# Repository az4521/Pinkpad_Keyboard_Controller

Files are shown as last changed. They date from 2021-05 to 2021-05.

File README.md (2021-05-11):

# Pinkpad_Keyboard_Controller
 This repo contains all the files that are needed to make the [Pinkpad](https://crafty.moe/pinkpad.htm)'s thinkpad X61 keyboard controller.
 
 BOM:
```
1x 0543630489 connector
1x Teensy LC
2x BSS138 (or compatible) sot23 NFET
4x 0603 10K Resistor
2x 0.1uf 0603 Capacitor
```

If you'd like to order the unpopulated board directly, I recommend ordering [This OSHPark project](https://oshpark.com/shared_projects/3l395XbG)

This board is based on [HDR/USB_Laptop_Keyboard_Controller](https://github.com/HDR/USB_Laptop_Keyboard_Controller), I've just removed the need for a reset generator in exchange for getting rid of the caps lock LED.

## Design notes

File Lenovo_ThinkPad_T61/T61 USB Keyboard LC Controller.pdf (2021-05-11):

This document will describe how I made a USB keyboard from a Lenovo ThinkPad T61 keyboard using a Teensy LC microcontroller. All associated files are in the Teensy LC folder under the Lenovo_Thinkpad_T61 folder at my Github repo. (https://github.com/thedalles77/USB_Laptop_Keyboard_Controller/tree/master/Example_Keyboards/Lenovo_ThinkPad_T61/) I initially designed a board for a Teensy 3.2 which taught me a lot about the keyboard. I used that information to design a Teensy LC board with the following changes from the 3.2 board.

1. The TrackPoint Clock and Data signals are translated to 5 volts with two BSS138 FETs and four 10K pullups. This was done because the Teensy LC does not have 5 volt tolerant I/Os.
2. The TrackPoint power-on-reset signal is created from a TLV810MDBZR in order to not use a Teensy I/O pin.
3. The Fn key switch is wired into the matrix by connecting FPC pin 1 to pin 11 and pin 36 to pin 20. Placing the Fn switch into the matrix was done to not use a Teensy I/O pin.
4. The Caps Lock signal on I/O #13 has a 715 ohm dropping resistor for a 2ma (low current) LED. This was done so the 3ma LED on the Teensy doesn’t need to be removed.
5. I rearranged the Teensy and FPC connector locations on the board to get away from the mounting post on the bottom of the keyboard. This layout change also keeps the circuit board underneath the keyboard so it can be hidden if mounting on a block of wood.

The picture below shows the Teensy LC circuit board connected to a ThinkPad T61 keyboard.

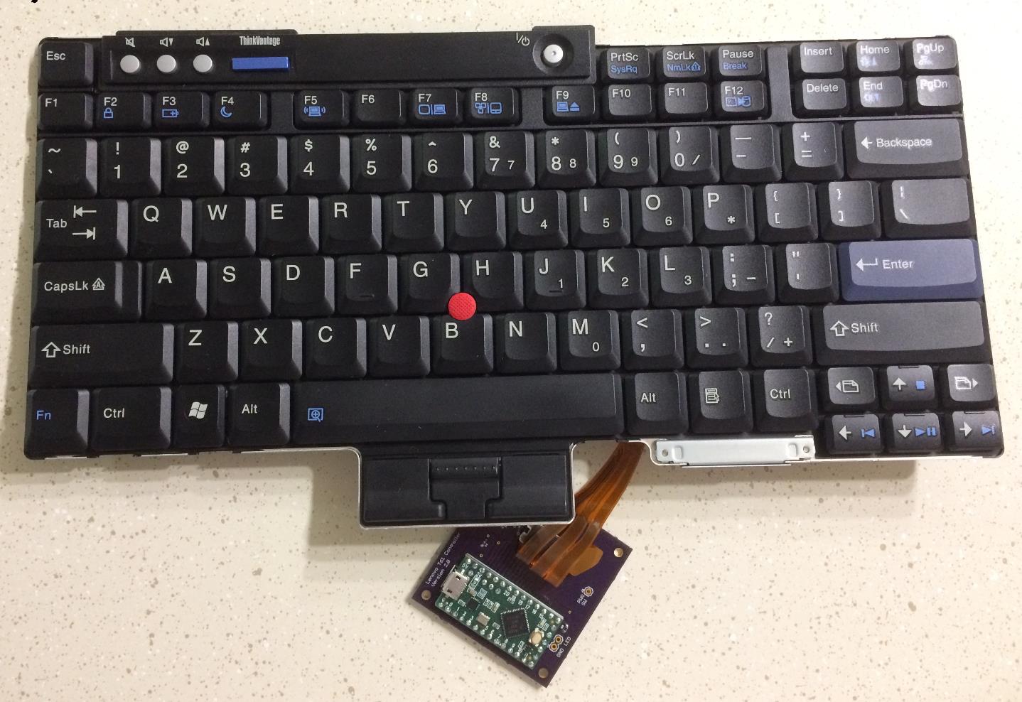
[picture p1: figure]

T61_LC_Scanner.brd file was sent to OSH Park for fabrication. The bare and assembled board is shown below. The Eagle board and schematic files are in the Eagle folder (https://github.com/thedalles77/USB_Laptop_Keyboard_Controller/tree/master/Example_Keyboards/Lenovo_ThinkPad_T61/Teensy%20LC/Eagle) at my Github repo.

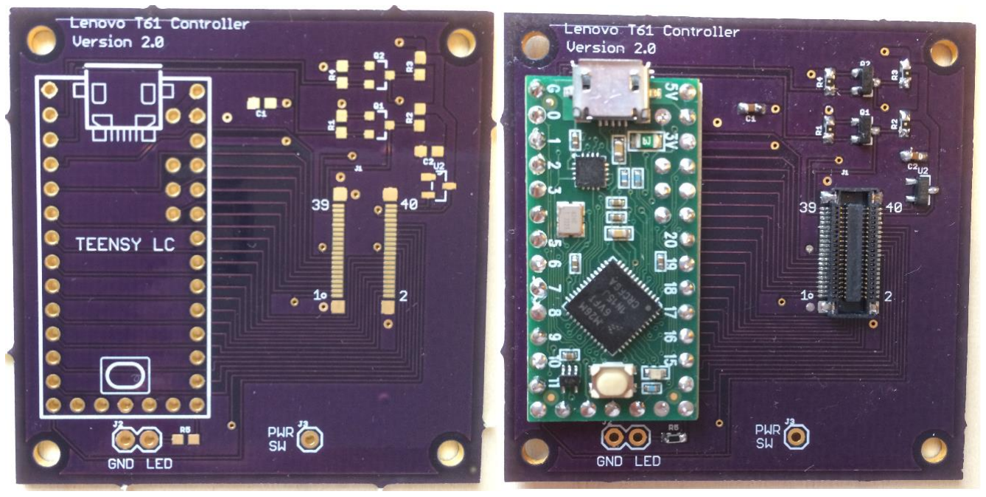
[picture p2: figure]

Parts List:
T61_LC_Scanner circuit board as shown above
Teensy LC from Amazon
Header pins and wire to connect the Teensy to the board

Digikey parts:
WM6787CT-ND 40 Pin Keyboard Connector Qty 1

TLV810MDBZR 4.38 Volt Reset Generator SOT23 Qty 1

BSS138CT-ND NFET SOT23 Qty 2

10K Resistors 0603 ¼ Watt 1% Qty 4

715 ohm Resistor 0603 1/10 Watt 1% Qty 1

0.1uf Ceramic Capacitor 0603 50V Y5V Qty 2

754-1592-ND 2ma Yellow LED axial lead Qty 1

Part placement and description shown below.

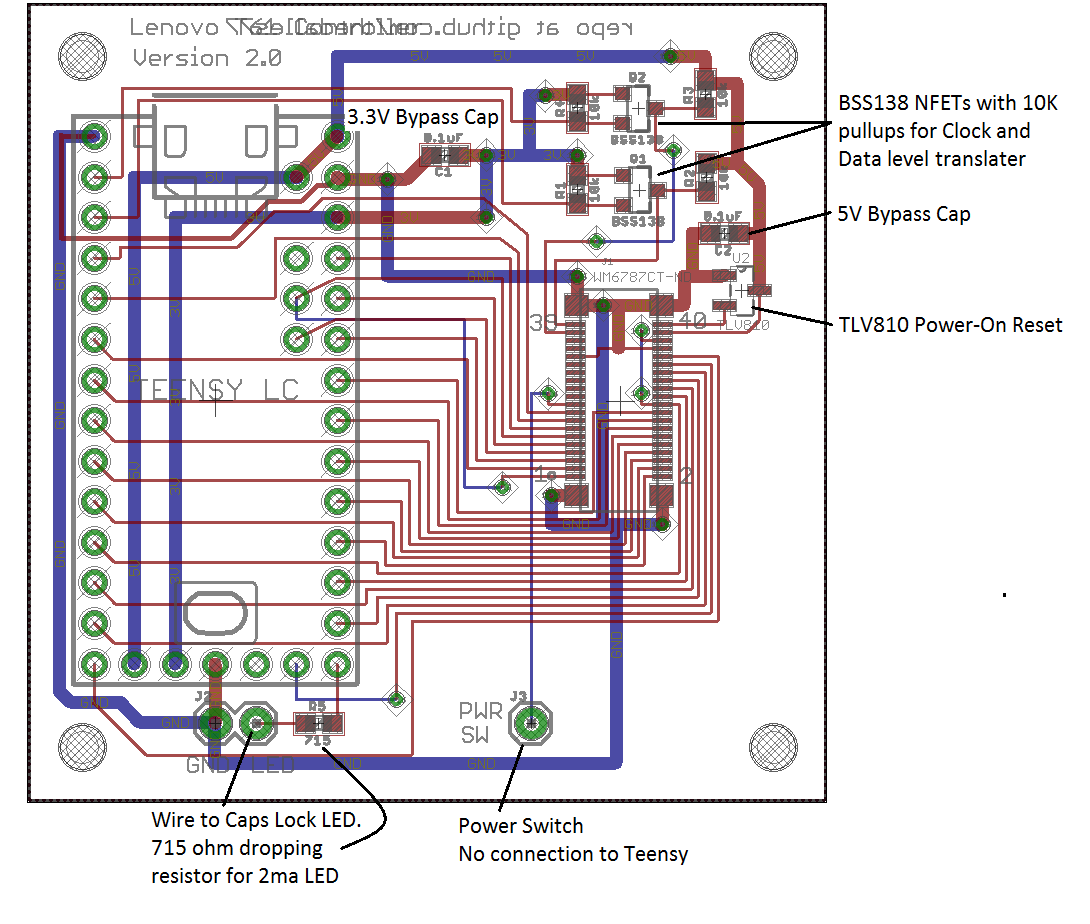
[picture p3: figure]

The WM6787CT-ND connector from Digikey will work with the Lenovo T61 keyboard but I did have some trouble with alignment, as originally discovered with the Teensy 3.2 board. Once I got the plug correctly installed in the socket, it worked fine so I don’t view this as a big problem. The alternative to using the Digikey connector is to search for the original JAE AA01B_S040VA1 connector or unsolder it from a broken motherboard. Forum posters have reported that the original connector is hard to find and only available in large lot sizes.

The keyboard connections to the Teensy LC pins are shown below.
Lenovo ThinkPad T61 FPC Connector | Teensy LC I/O number | T61 Schematic Signal Name
1 | 24 | HOTKEY
2 | 16 | DRV<4>
3 | 4 | SENSE<5>
4 | 8 | DRV<5>
5 | 21 | SENSE<0>
6 | 17 | DRV<8>

7 | 25 | SENSE<3>
8 | 7 | DRV<6>
9 | 22 | SENSE<2>
10 | 18 | DRV<3>
11 | 24 | SENSE<4>
12 | 6 | DRV<7>
13 | 23 | SENSE<1>
14 | 19 | DRV<2>
15 | 3 | SENSE<6>
16 | 5 | DRV<10>
17 | 2 | SENSE<7>
18 | 20 | DRV<1>
19 | PWR SW Pad | PWR SW
20 | 9 | DRV<9>
21 | No connect | NC
22 | 15 | DRV<0>
23 | No connect | NC
24 | 10 | DRV<11>
25 | No connect | KBDID0
26 | 14 | DRV<14>
27 | No connect | KBDID1
28 | 11 | DRV<12>
29 | No connect | KBDID2
30 | 26 | DRV<15>
31 | Teensy GND | KBDID RTN
32 | 12 | DRV<13>
33 | No connect | NC
34 | Teensy GND | PWR SW RTN
35 | No connect | NC
36 | 9 | HOTKEY RTN
37 | 0 | TP_DATA
38 | Teensy 5V | TP_5V
39 | 1 | TP_CLK
40 | TLV810 | TP_RESET
41 thru 44 | Teensy GND | GND

The Eagle schematic for the connections on the circuit board is given below. This schematic is in the Eagle folder at my repo.

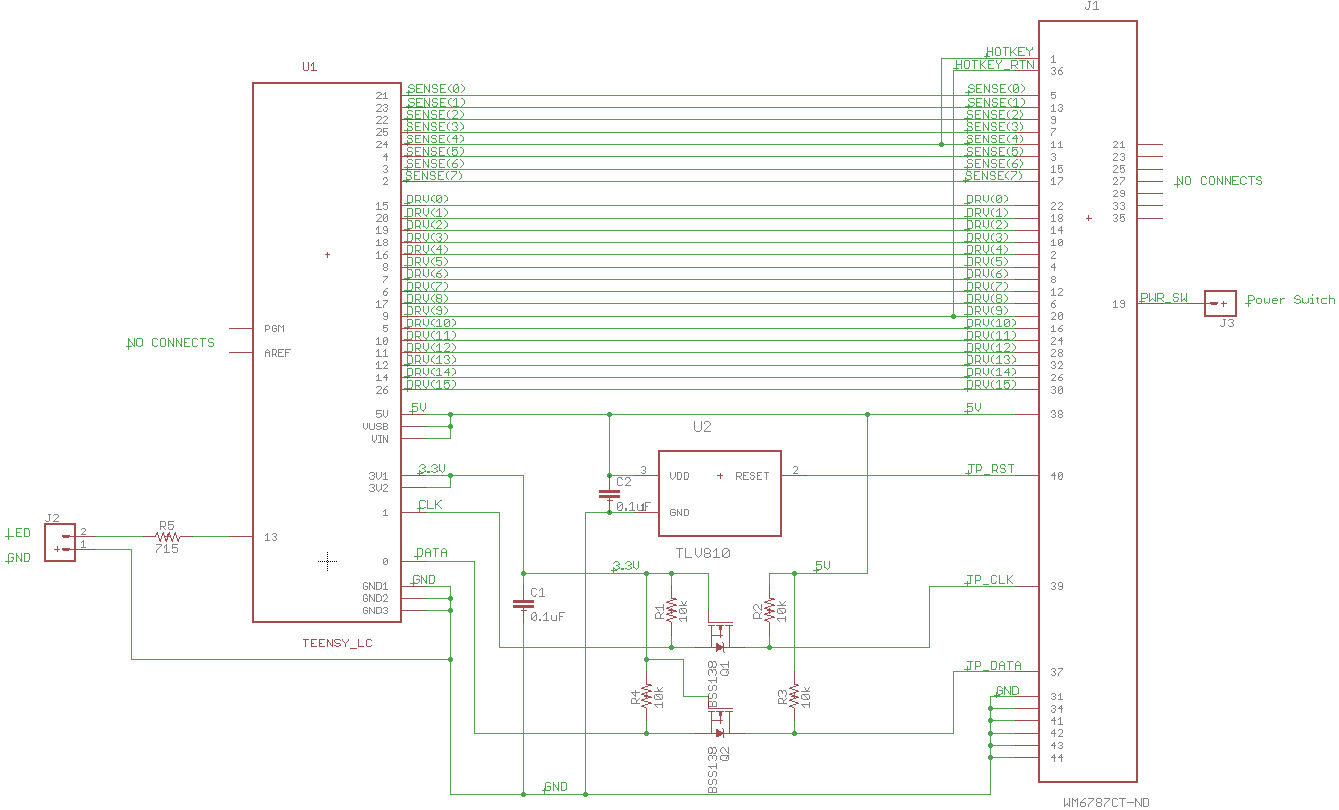
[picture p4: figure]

It was easy to find a Lenovo motherboard schematic online that provided me with the connector pins for the DRV and SENSE signals. The Matrix_Decoder_T61_LC.ino code at my repo scans the DRV and SENSE pins and sends key press connection characters over USB for capture by an editor. The key press results in the file Lenovo_T61_LC_io_list.txt at my repo (https://github.com/thedalles77/USB_Laptop_Keyboard_Controller/tree/master/Example_Keyboards/Lenovo_ThinkPad_T61/Teensy%20LC/Eagle) were used to build the matrix table shown below. The Teensy inputs aka Sense<0> thru <7> are the columns across the top and the Teensy outputs aka Drive<0> thru <15> are the rows on the side.

Matrix for the LC Lenovo ThinkPad T61 – Keyboard Part Number 42T3177

Teensy 3.2 I/O Number | Sense<0> I/O 21 | Sense<1> I/O 23 | Sense<2> I/O 22 | Sense<3> I/O 25 | Sense<4> I/O 24 | Sense<5> I/O 4 | Sense<6 > I/O 3 | Sense<7> I/O 2
Drive<0> I/O 15 | Back-Tick | 1 | Q | Tab | A | Esc | Z
Drive<1> I/O 20 | F1 | 2 | W | Caps-Lock | S | | X
Drive<2> I/O 19 | F2 | 3 | E | F3 | D | F4 | C
Drive<3> I/O 18 | 5 | 4 | R | T | F | G | V | B
Drive<4> I/O 16 | 6 | 7 | U | Y | J | H | M | N
Drive<5> I/O 8 | Equal | 8 | I | Right-Brace | K | F6 | Comma
Drive<6> I/O 7 | F8 | 9 | O | F7 | L | | Period
Drive<7> I/O 6 | Minus | 0 | P | Left-Brace | Semi-colon | Quote | | Forward-Slash
Drive<8> I/O 17 | F9 | F10 | | Back-Space | Back-Slash | F5 | Enter | Space
Drive<9> I/O 9 | Insert | F12 | | | Fn | | | Arrow-Right
Drive<10> I/O 5 | Delete | F11 | Volume-Up | Volume-Down | Mute | Think-Vantage | | Arrow-Down
Drive<11> I/O 10 | Page-Up | Page-Down | GUI | | Menu | | Page-Left | Page-Right
Drive<12> I/O 11 | Home | End | | | | Arrow-Up | Pause | Arrow-Left
Drive<13> I/O 12 | | Print-Screen | Scroll-Lock | | | Alt-L | | Alt-R
Drive<14> I/O 14 | | | | Shift-L | | | Shift-R
Drive<15> I/O 26 | Cntrl-L | | | | | | Cntrl_R

The Fn “Hotkey” has its own dedicated pins but has been wired into the matrix at Drive<9> & Sense<4> in order to save an I/O pin on the Teensy LC.

With the key matrix information shown above, you can load the TMK software into the Teensy. I have written a keyboard and trackpoint routine as a simple alternative called Lenovo_T61_KBandTP_LC.ino. (https://github.com/thedalles77/USB_Laptop_Keyboard_Controller/tree/master/Example_Keyboards/Lenovo_ThinkPad_T61/) It uses the Teensyduino "Micro-Manager Method" to send keys over USB. All of the normal and modifier keys are supported but only the volume control multimedia keys are part of this routine. A description of the Teensyduino keyboard functions is at www.pjrc.com/teensy/td_keyboard.html.

The PS/2 code for the Trackpoint was coded based on the timing diagrams and uses the PJRC Mouse functions to send over USB. A watchdog timer in the "while loops" won’t let the code hang if the Teensy misses a clock edge. This can happen when the Teensy is interrupted by the USB port to receive the keyboard_leds (CAPS LOCK) data.

I have found that the alignment tab on the T61 keyboard connector can be broken by forcing it into the WM6787CT-ND Digikey motherboard connector. The picture below shows how one tab is missing. This probably happened when I tried attaching the connectors without having them properly aligned. The keyboard can still be plugged into the WM6787CT-ND or JAE AA01B_S040VA1 motherboard connector but it may take many tries to get the alignment correct. I have a second keyboard that has both alignment tabs broken off but it still works fine.

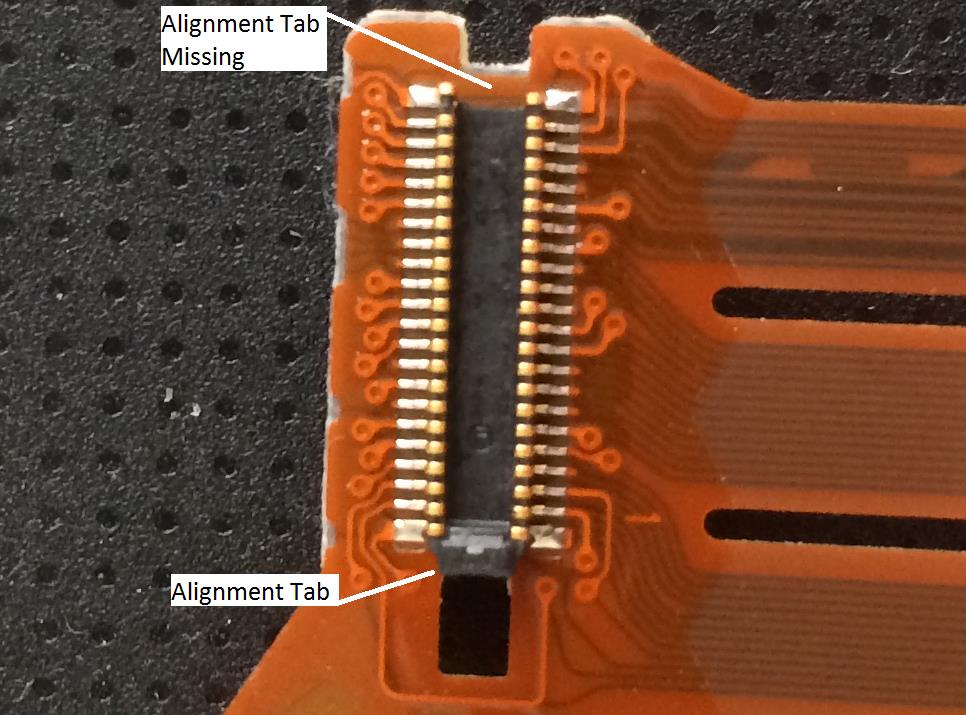
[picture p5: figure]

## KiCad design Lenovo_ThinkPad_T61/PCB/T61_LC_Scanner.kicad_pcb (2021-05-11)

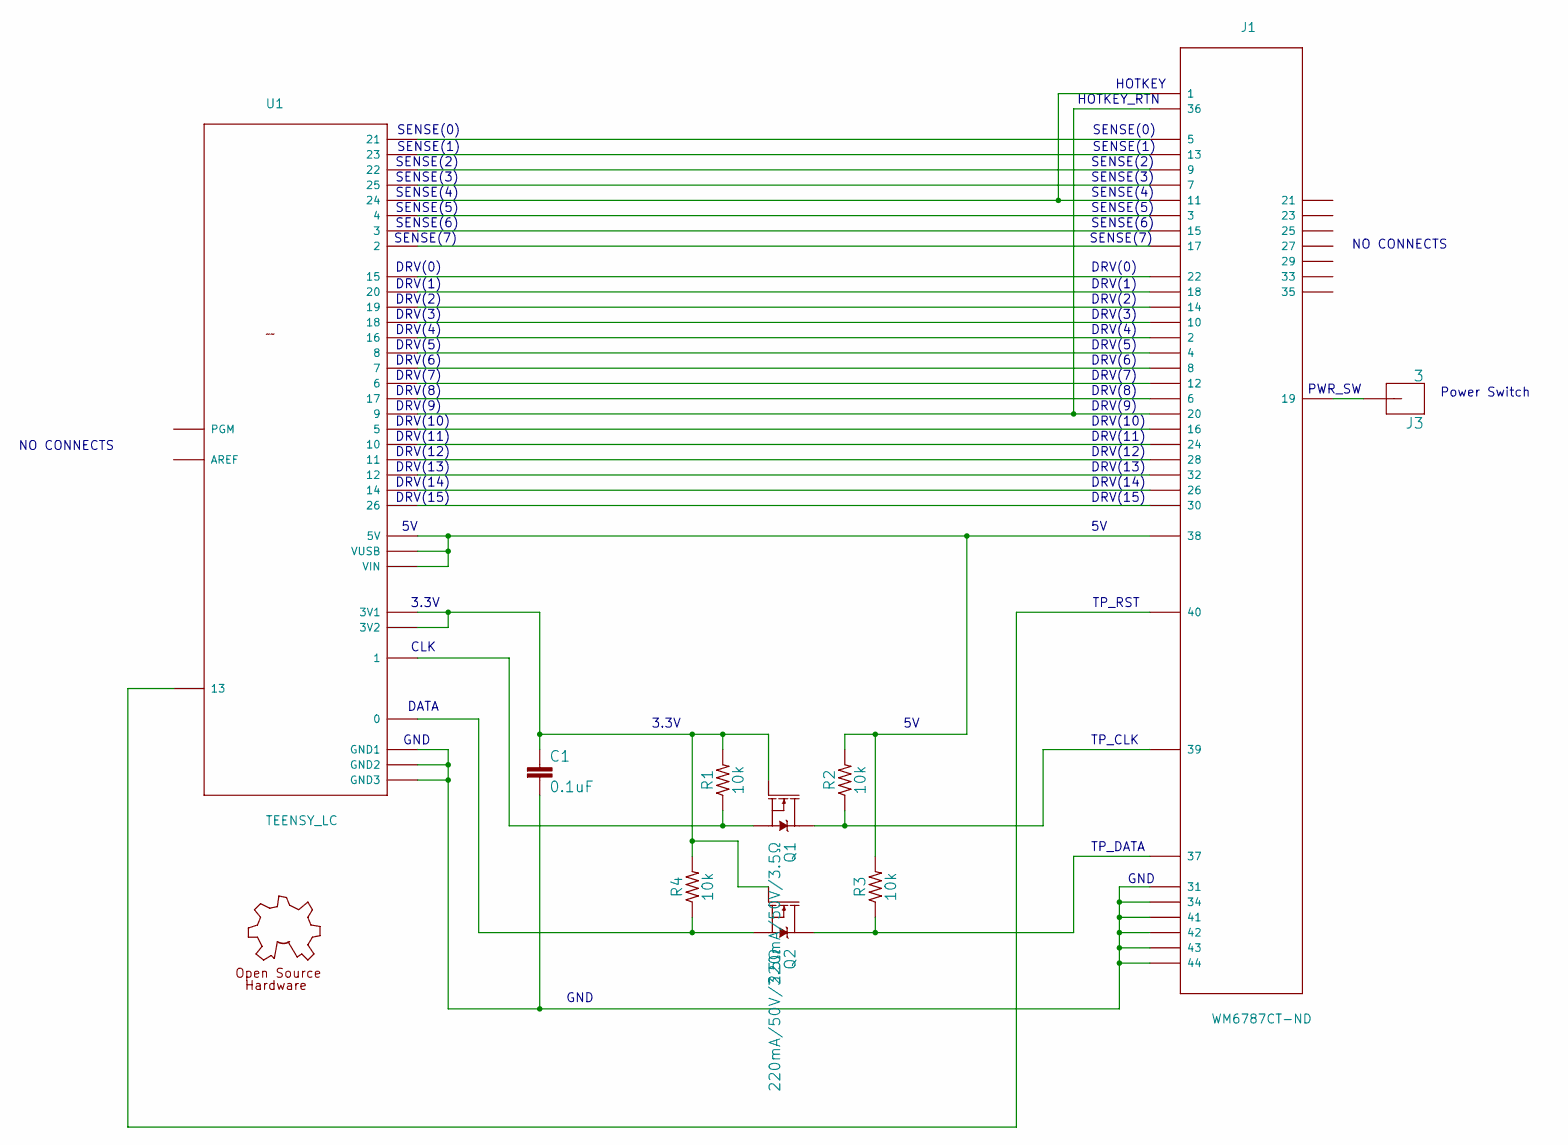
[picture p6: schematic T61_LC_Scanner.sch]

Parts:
C1: 0.1uF; 0603
GOLD_ORB_SM1: OSHWLOGOLOGO5MM; OSHW_5MM
J1: WM6787CT-ND
J3: 3; 1X01
Q1, Q2: 220mA/50V/3.5Ω; SOT23-3
R1, R2, R3, R4: 10k; 0603
U1: TEENSY_LC

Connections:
unnamed: C1.1, Q1.1 (G), Q2.1 (G), R1.2, R4.2, U1.3V1, U1.3V2
unnamed: C1.2, J1.P$31 (31), J1.P$34 (34), J1.P$41 (43), J1.P$42 (44), J1.P$43 (41), J1.P$44 (42), U1.GND1, U1.GND2, U1.GND3
unnamed: J1.P$1 (1), J1.P$11 (11), U1.24
unnamed: J1.P$2 (2), U1.16
unnamed: J1.P$3 (3), U1.4
unnamed: J1.P$4 (4), U1.8
unnamed: J1.P$5 (5), U1.21
unnamed: J1.P$6 (6), U1.17
unnamed: J1.P$7 (7), U1.25
unnamed: J1.P$8 (8), U1.7
unnamed: J1.P$9 (9), U1.22
unnamed: J1.P$10 (10), U1.18
unnamed: J1.P$12 (12), U1.6
unnamed: J1.P$13 (13), U1.23
unnamed: J1.P$14 (14), U1.19
unnamed: J1.P$15 (15), U1.3
unnamed: J1.P$16 (16), U1.5
unnamed: J1.P$17 (17), U1.2
unnamed: J1.P$18 (18), U1.20
unnamed: J1.P$19 (19), J3.1
unnamed: J1.P$20 (20), J1.P$36 (36), U1.9
unnamed: J1.P$22 (22), U1.15
unnamed: J1.P$24 (24), U1.10
unnamed: J1.P$26 (26), U1.14
unnamed: J1.P$28 (28), U1.11
unnamed: J1.P$30 (30), U1.26
unnamed: J1.P$32 (32), U1.12
unnamed: J1.P$37 (37), Q2.3 (D), R3.1
unnamed: J1.P$38 (38), R2.2, R3.2, U1.5V, U1.VIN, U1.VUSB
unnamed: J1.P$39 (39), Q1.3 (D), R2.1
unnamed: J1.P$40 (40), U1.13
unnamed: Q1.2 (S), R1.1, U1.1
unnamed: Q2.2 (S), R4.1, U1.0

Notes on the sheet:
Power Switch
HOTKEY
HOTKEY_RTN
SENSE(0)
SENSE(1)
SENSE(2)
SENSE(3)
SENSE(4)
SENSE(5)
SENSE(6)
SENSE(7)
DRV(0)
DRV(1)
DRV(2)
DRV(3)
DRV(4)
DRV(5)
DRV(6)
DRV(7)
DRV(8)
DRV(9)
DRV(10)
DRV(11)
DRV(12)
DRV(13)
DRV(14)
DRV(15)
TP_RST
TP_CLK
TP_DATA
GND
NO CONNECTS
PWR_SW
DATA
CLK
3.3V

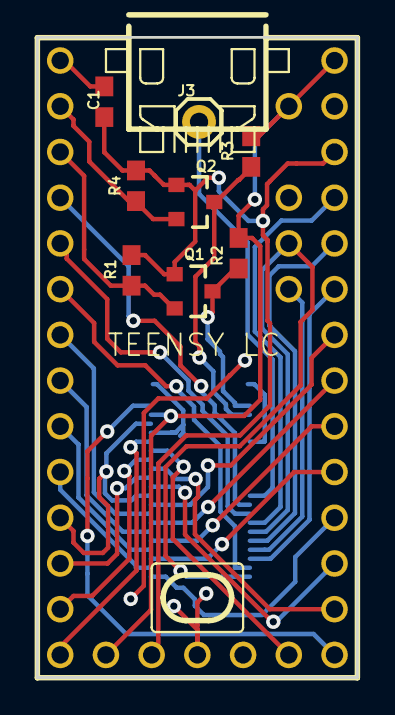
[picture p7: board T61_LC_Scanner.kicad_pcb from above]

Board: 2 copper layers, 17.8 x 35.6 mm, 10 parts (0 on the bottom side), 33 nets.

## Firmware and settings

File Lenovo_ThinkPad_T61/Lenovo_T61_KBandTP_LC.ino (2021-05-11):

/* Copyright 2018 Frank Adams
   Licensed under the Apache License, Version 2.0 (the "License");
   you may not use this file except in compliance with the License.
   You may obtain a copy of the License at
       http://www.apache.org/licenses/LICENSE-2.0
   Unless required by applicable law or agreed to in writing, software
   distributed under the License is distributed on an "AS IS" BASIS,
   WITHOUT WARRANTIES OR CONDITIONS OF ANY KIND, either express or implied.
   See the License for the specific language governing permissions and
   limitations under the License.
*/
// This software controls a Lenovo ThinkPad T61 Laptop Keyboard and PS/2 Trackpoint using a Teensy LC on 
// a daughterboard with a 44 pin FPC connector. The keyboard part number is 42T3177.
// This routine uses the Teensyduino "Micro-Manager Method" to send Normal and Modifier 
// keys over USB. Only the volume control multi-media keys are supported by this routine.
// Description of Teensyduino keyboard functions is at www.pjrc.com/teensy/td_keyboard.html
// The ps/2 code uses the USB PJRC Mouse functions at www.pjrc.com/teensy/td_mouse.html 
// The ps/2 code has a watchdog timer so the code can't hang if a clock edge is missed.
// In the Arduino IDE, select Tools, Teensy LC. Also under Tools, select Keyboard+Mouse+Joystick
//
// Revision History
// Rev 1.0 - Nov 20, 2018 - Original Release
// Rev 1.1 - Dec 2, 2018 - Replaced ps/2 trackpoint code from playground arduino with my own code 
// Rev 1.2 - July 16, 2019 - Check if slots are full when detecting a key press
// Rev 1.3 - Some time 2021 idk, pinkpad stuff. - Add a few extensions for media keys and things
//
#define MODIFIERKEY_FN 0x8f   // give Fn key a HID code

//application control keys
#define KEY_FORWARD (0xE400 + 0x225)
#define KEY_BACK    (0xE400 + 0x224)

//media keys
#define KEY_STOP      (0xE400 | 0xB7)
#define KEY_PLAYPAUSE (0xE400 | 0xCD)
#define KEY_NEXT      (0xE400 | 0xB5)
#define KEY_PREVIOUS  (0xE400 | 0xB6)

//ACPI key
#define KEY_SLEEP (0xE200 | 0x82)

//nonstandard microsoft extensions
#define KEY_BRIGHTNESS_UP   (0xE400 | 0x6F)
#define KEY_BRIGHTNESS_DOWN (0xE400 | 0x70)
#define KEY_RADIO_TOGGLE    (0xE200 | 0xC6) //doesnt even work, thanks MS

//just do whatever with this later on
#define KEY_THINKVANTAGE 0




// Trackpoint signals
#define TP_DATA 0   // ps/2 data to trackpoint (via BSS138 level translator)
#define TP_CLK 1    // ps/2 clock to trackpoint (via BSS138 level translator)
// Keyboard LEDs
#define CAPS_LED 13   // includes 715 ohm resistor for 2ma LED 
// Set the keyboard row & column size
const byte rows_max = 16; // sets the number of rows in the matrix
const byte cols_max = 8; // sets the number of columns in the matrix
//
// Load the normal key matrix with the Teensyduino key names described at www.pjrc.com/teensy/td_keyboard.html
// A zero indicates no normal key at that location.
//
int normal[rows_max][cols_max] = {
  {KEY_TILDE,KEY_1,KEY_Q,KEY_TAB,KEY_A,KEY_ESC,KEY_Z,0},
  {KEY_F1,KEY_2,KEY_W,KEY_CAPS_LOCK,KEY_S,0,KEY_X,0},
  {KEY_F2,KEY_3,KEY_E,KEY_F3,KEY_D,KEY_F4,KEY_C,0},
  {KEY_5,KEY_4,KEY_R,KEY_T,KEY_F,KEY_G,KEY_V,KEY_B},
  {KEY_6,KEY_7,KEY_U,KEY_Y,KEY_J,KEY_H,KEY_M,KEY_N},
  {KEY_EQUAL,KEY_8,KEY_I,KEY_RIGHT_BRACE,KEY_K,KEY_F6,KEY_COMMA,0},
  {KEY_F8,KEY_9,KEY_O,KEY_F7,KEY_L,0,KEY_PERIOD,0},
  {KEY_MINUS,KEY_0,KEY_P,KEY_LEFT_BRACE,KEY_SEMICOLON,KEY_QUOTE,0,KEY_SLASH},
  {KEY_F9,KEY_F10,0,KEY_BACKSPACE,KEY_BACKSLASH,KEY_F5,KEY_ENTER,KEY_SPACE},
  {KEY_INSERT,KEY_F12,0,0,0,0,0,KEY_RIGHT},  
  {KEY_DELETE,KEY_F11,0,0,0,0,0,KEY_DOWN},
  {KEY_PAGE_UP,KEY_PAGE_DOWN,0,0,KEY_MENU,0,0,0},
  {KEY_HOME,KEY_END,0,0,0,KEY_UP,KEY_PAUSE,KEY_LEFT},
  {0,KEY_PRINTSCREEN,KEY_SCROLL_LOCK,0,0,0,0,0},
  {0,0,0,0,0,0,0,0},
  {0,0,0,0,0,0,0,0}
};
// Load the modifier key matrix with key names at the correct row-column location. 
// A zero indicates no modifier key at that location.
int modifier[rows_max][cols_max] = {
  {0,0,0,0,0,0,0,0},
  {0,0,0,0,0,0,0,0},
  {0,0,0,0,0,0,0,0},
  {0,0,0,0,0,0,0,0},
  {0,0,0,0,0,0,0,0},
  {0,0,0,0,0,0,0,0},
  {0,0,0,0,0,0,0,0},
  {0,0,0,0,0,0,0,0},   
  {0,0,0,0,0,0,0,0},
  {0,0,0,0,MODIFIERKEY_LEFT_CTRL,0,0,0},
  {0,0,0,0,0,0,0,0},
  {0,0,MODIFIERKEY_GUI,0,0,0,0,0},    
  {0,0,0,0,0,0,0,0},
  {0,0,0,0,0,MODIFIERKEY_LEFT_ALT,0,MODIFIERKEY_RIGHT_ALT},
  {0,0,0,MODIFIERKEY_LEFT_SHIFT,0,0,MODIFIERKEY_RIGHT_SHIFT,0},
  {MODIFIERKEY_FN,0,0,0,0,0,MODIFIERKEY_RIGHT_CTRL,0}
};
// Load the media key matrix with key names at the correct row-column location. 
// A zero indicates no media key at that location.
int media[rows_max][cols_max] = {
  {0,0,0,0,0,0,0,0},
  {0,0,0,0,0,0,0,0},
  {0,0,0,0,0,0,0,0},
  {0,0,0,0,0,0,0,0},
  {0,0,0,0,0,0,0,0},
  {0,0,0,0,0,0,0,0},
  {0,0,0,0,0,0,0,0},
  {0,0,0,0,0,0,0,0},   
  {0,0,0,0,0,0,0,0},
  {0,0,0,0,0,0,0,0},
  {0,0,KEY_MEDIA_VOLUME_INC,KEY_MEDIA_VOLUME_DEC,KEY_MEDIA_MUTE,KEY_THINKVANTAGE,0,0},
  {0,0,0,0,0,0,KEY_BACK,KEY_FORWARD},   
  {0,0,0,0,0,0,0,0},
  {0,0,0,0,0,0,0,0},
  {0,0,0,0,0,0,0,0},
  {0,0,0,0,0,0,0,0}
};
// Initialize the old_key matrix with one's. 
// 1 = key not pressed, 0 = key is pressed
boolean old_key[rows_max][cols_max] = {
  {1,1,1,1,1,1,1,1},
  {1,1,1,1,1,1,1,1},
  {1,1,1,1,1,1,1,1},
  {1,1,1,1,1,1,1,1},
  {1,1,1,1,1,1,1,1},
  {1,1,1,1,1,1,1,1},
  {1,1,1,1,1,1,1,1},
  {1,1,1,1,1,1,1,1},
  {1,1,1,1,1,1,1,1},
  {1,1,1,1,1,1,1,1},
  {1,1,1,1,1,1,1,1},
  {1,1,1,1,1,1,1,1},
  {1,1,1,1,1,1,1,1},
  {1,1,1,1,1,1,1,1},
  {1,1,1,1,1,1,1,1},
  {1,1,1,1,1,1,1,1}
};
//
// Define the Teensy LC I/O numbers 
//
// Row FPC pin # 22,18,14,10,02,04,08,12,06,20,16,24,28,32,26,30
// Teensy I/O  # 15,20,19,18,16,08,07,06,17,09,05,10,11,12,14,26
int Row_IO[rows_max] = {15,20,19,18,16,8,7,6,17,9,5,10,11,12,14,26}; // Teensy LC I/O numbers for rows
//
// Column FPC pin # 05,13,09,07,11,03,15,17
// Teensy I/O     # 21,23,22,25,24,04,03,02
int Col_IO[cols_max] = {21,23,22,25,24,4,3,2};  // Teensy LC I/O numbers for columns
//
// Declare variables that will be used by functions
boolean trackpoint_error = LOW; // sent high when touch pad routine times out
boolean slots_full = LOW; // Goes high when slots 1 thru 6 contain normal keys
// slot 1 thru slot 6 hold the normal key values to be sent over USB. 
int slot1 = 0; //value of 0 means the slot is empty and can be used.  
int slot2 = 0; 
int slot3 = 0; 
int slot4 = 0; 
int slot5 = 0; 
int slot6 = 0;
//
int mod_shift_l = 0; // These variables are sent over USB as modifier keys.
int mod_shift_r = 0; // Each is either set to 0 or MODIFIER_ ... 
int mod_ctrl_l = 0;   
int mod_ctrl_r = 0;
int mod_alt_l = 0;
int mod_alt_r = 0;
int mod_gui = 0;
//
// **************Functions common to keyboard and trackpoint**************************
//
// Function to set a pin to high impedance (acts like open drain output)
void go_z(int pin)
{
  pinMode(pin, INPUT);
  digitalWrite(pin, HIGH);
}
//
// Function to set a pin as an input with a pullup
void go_pu(int pin)
{
  pinMode(pin, INPUT_PULLUP);
  digitalWrite(pin, HIGH);
}
//
// Function to send a pin to a logic low
void go_0(int pin)
{
  pinMode(pin, OUTPUT);
  digitalWrite(pin, LOW);
}
//
// Function to send a pin to a logic high
void go_1(int pin)
{
  pinMode(pin, OUTPUT);
  digitalWrite(pin, HIGH);
}
// *****************Functions for Trackpoint***************************
//
// Function to send the trackpoint a byte of data (command)
//
void tp_write(char send_data)  
{
  unsigned int timeout = 200; // break out of loop if over this value in msec
  elapsedMillis watchdog; // zero the watchdog timer clock
  char odd_parity = 0; // clear parity bit count
// Enable the bus by floating the clock and data
  go_z(TP_CLK); //
  go_z(TP_DATA); //
  delayMicroseconds(250); // wait before requesting the bus
  go_0(TP_CLK); //   Send the Clock line low to request to transmit data
  delayMicroseconds(100); // wait for 100 microseconds per bus spec
  go_0(TP_DATA); //  Send the Data line low (the start bit)
  delayMicroseconds(1); //
  go_z(TP_CLK); //   Release the Clock line so it is pulled high
  delayMicroseconds(1); // give some time to let the clock line go high
  while (digitalRead(TP_CLK) == HIGH) { // loop until the clock goes low
    if (watchdog >= timeout) { //check for infinite loop
      trackpoint_error = HIGH; // set error flag       
      break; // break out of infinite loop
    }
  }
// send the 8 bits of send_data 
  for (int j=0; j<8; j++) {
    if (send_data & 1) {  //check if lsb is set
      go_z(TP_DATA); // send a 1 to TP
      odd_parity = odd_parity + 1; // keep running total of 1's sent
    }
    else {
      go_0(TP_DATA); // send a 0 to TP
    }
    delayMicroseconds(1); // delay to let the clock settle out
    while (digitalRead(TP_CLK) == LOW) { // loop until the clock goes high
      if (watchdog >= timeout) { //check for infinite loop
        trackpoint_error = HIGH; // set error flag       
        break; // break out of infinite loop
      }
    }
    delayMicroseconds(1); // delay to let the clock settle out
    while (digitalRead(TP_CLK) == HIGH) { // loop until the clock goes low
      if (watchdog >= timeout) { //check for infinite loop
        trackpoint_error = HIGH; // set error flag       
        break; // break out of infinite loop
      }
    }  
    send_data = send_data >> 1; // shift data right by 1 to prepare for next loop
  }
// send the parity bit
  if (odd_parity & 1) {  //check if lsb of parity is set
    go_0(TP_DATA); // already odd so send a 0 to TP
  }
  else {
    go_z(TP_DATA); // send a 1 to TP to make parity odd
  }   
  delayMicroseconds(1); // delay to let the clock settle out
  while (digitalRead(TP_CLK) == LOW) { // loop until the clock goes high
    if (watchdog >= timeout) { //check for infinite loop
      trackpoint_error = HIGH; // set error flag       
      break; // break out of infinite loop
    }
  }
  delayMicroseconds(1); // delay to let the clock settle out
  while (digitalRead(TP_CLK) == HIGH) { // loop until the clock goes low
    if (watchdog >= timeout) { //check for infinite loop
      trackpoint_error = HIGH; // set error flag       
      break; // break out of infinite loop
    }
  }
  go_z(TP_DATA); //  Release the Data line so it goes high as the stop bit
  delayMicroseconds(80); // testing shows delay at least 40us 
  while (digitalRead(TP_CLK) == HIGH) { // loop until the clock goes low
    if (watchdog >= timeout) { //check for infinite loop
      trackpoint_error = HIGH; // set error flag       
      break; // break out of infinite loop
    }
  }
  delayMicroseconds(1); // wait to let the data settle
  if (digitalRead(TP_DATA)) { // Ack bit s/b low if good transfer
    trackpoint_error = HIGH; //bad ack bit so set the error flag
  }
  while ((digitalRead(TP_CLK) == LOW) || (digitalRead(TP_DATA) == LOW)) { // loop if clock or data are low
    if (watchdog >= timeout) { //check for infinite loop
      trackpoint_error = HIGH; // set error flag       
      break; // break out of infinite loop
    }
  }
// Inhibit the bus so the tp only talks when we're listening
  go_0(TP_CLK);
}
//
// Function to get a byte of data from the trackpoint
//
char tp_read(void)
{
  unsigned int timeout = 200; // breakout of loop if over this value in msec
  elapsedMillis watchdog; // zero the watchdog timer clock
  char rcv_data = 0; // initialize to zero
  char mask = 1; // shift a 1 across the 8 bits to select where to load the data
  char rcv_parity = 0; // count the ones received
  go_z(TP_CLK); // release the clock
  go_z(TP_DATA); // release the data
  delayMicroseconds(5); // delay to let clock go high
  while (digitalRead(TP_CLK) == HIGH) { // loop until the clock goes low
    if (watchdog >= timeout) { //check for infinite loop
      trackpoint_error = HIGH; // set error flag       
      break; // break out of infinite loop
    }
  }
  if (digitalRead(TP_DATA)) { // Start bit s/b low from tp
    trackpoint_error = HIGH; // No start bit so set the error flag
  }  
  delayMicroseconds(1); // delay to let the clock settle out
  while (digitalRead(TP_CLK) == LOW) { // loop until the clock goes high
    if (watchdog >= timeout) { //check for infinite loop
      trackpoint_error = HIGH; // set error flag       
      break; // break out of infinite loop
    }
  }
  for (int k=0; k<8; k++) {  
    delayMicroseconds(1); // delay to let the clock settle out
    while (digitalRead(TP_CLK) == HIGH) { // loop until the clock goes low
      if (watchdog >= timeout) { //check for infinite loop
        trackpoint_error = HIGH; // set error flag       
        break; // break out of infinite loop
      }
    }
    if (digitalRead(TP_DATA)) { // check if data is high
      rcv_data = rcv_data | mask; // set the appropriate bit in the rcv data
      rcv_parity++; // increment the parity bit counter
    }
    mask = mask << 1;
    delayMicroseconds(1); // delay to let the clock settle out
    while (digitalRead(TP_CLK) == LOW) { // loop until the clock goes high
      if (watchdog >= timeout) { //check for infinite loop
        trackpoint_error = HIGH; // set error flag       
        break; // break out of infinite loop
      }
    }
  }
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
void loop() {   
// *************Keyboard Main**************
// Scan keyboard matrix with an outer loop that drives each row low and an inner loop that reads every column (with pull ups).
// The routine looks at each key's present state (by reading the column input pin) and also the previous state from the last scan
// that was 30msec ago. The status of a key that was just pressed or just released is sent over USB and the state is saved in the old_key matrix. 
// The keyboard keys will read as logic low if they are pressed (negative logic).
// The old_key matrix also uses negative logic (low=pressed). 
//
  for (int x = 0; x < rows_max; x++) {   // loop thru the rows
    go_0(Row_IO[x]); // Activate Row (send it low)
    delayMicroseconds(10); // give the row time to go low and settle out
    for (int y = 0; y < cols_max; y++) {   // loop thru the columns
// **********Modifier keys
      if (modifier[x][y] != 0) {  // check if modifier key exists at this location in the array (a non-zero value)
        if (!digitalRead(Col_IO[y]) && (old_key[x][y])) {  // Read column to see if key is low (pressed) and was previously not pressed
          if (modifier[x][y] != MODIFIERKEY_FN) {   // Exclude Fn modifier key
            load_mod(modifier[x][y]); // function reads which modifier key is pressed and loads it into the appropriate mod_... variable   
            send_mod(); // function sends the state of all modifier keys over usb including the one that just got pressed
            old_key[x][y] = LOW; // Save state of key as "pressed"
          }
          else {
            Fn_pressed = LOW; // Fn status variable is active low
            old_key[x][y] = LOW; // old_key state is "pressed" (active low)
          }
        }
        else if (digitalRead(Col_IO[y]) && (!old_key[x][y])) {  //check if key is not pressed and was previously pressed
          if (modifier[x][y] != MODIFIERKEY_FN) { // Exclude Fn modifier key 
            clear_mod(modifier[x][y]); // function reads which modifier key was released and loads 0 into the appropriate mod_... variable
            send_mod(); // function sends all mod's over usb including the one that just released
            old_key[x][y] = HIGH; // Save state of key as "not pressed"
          }
          else {
            Fn_pressed = HIGH; // Fn is no longer active
            old_key[x][y] = HIGH; // old_key state is "not pressed"
          }
        }
      } 
// ***********end of modifier section
//
// ***********Normal keys section
      else if (normal[x][y] != 0) {  // check if normal key exists at this location in the array (a non-zero value)
        if (!digitalRead(Col_IO[y]) && (old_key[x][y]) && (!slots_full)) { // check if key pressed and not previously pressed and slots not full
          old_key[x][y] = LOW; // Save state of key as "pressed"
          if ((normal[x][y] == KEY_SCROLL_LOCK) && (!Fn_pressed)) { // check for special case of Num Lock Key
            load_slot(KEY_NUM_LOCK); // update first available slot with Num Lock instead of Scroll Lock
          } else if ((normal[x][y] == KEY_UP) && (!Fn_pressed)) { //media keys
            Keyboard.press(KEY_STOP);
          } else if ((normal[x][y] == KEY_DOWN) && (!Fn_pressed)) {
            Keyboard.press(KEY_PLAYPAUSE);
          } else if ((normal[x][y] == KEY_RIGHT) && (!Fn_pressed)) {
            Keyboard.press(KEY_NEXT);
          } else if ((normal[x][y] == KEY_LEFT) && (!Fn_pressed)) {
            Keyboard.press(KEY_PREVIOUS);
          } else if ((normal[x][y] == KEY_F4) && (!Fn_pressed)) {
            Keyboard.press(KEY_SLEEP);
          } else if ((normal[x][y] == KEY_F5) && (!Fn_pressed)) {
            Keyboard.press(KEY_RADIO_TOGGLE);
          } else if ((normal[x][y] == KEY_HOME) && (!Fn_pressed)) {
            Keyboard.press(KEY_BRIGHTNESS_UP);
          } else if ((normal[x][y] == KEY_END) && (!Fn_pressed)) {
            Keyboard.press(KEY_BRIGHTNESS_DOWN);
          }
          else {
            load_slot(normal[x][y]); //update first available slot with normal key name
          }
          send_normals(); // send all slots over USB including the key that just got pressed 
        }          
        else if (digitalRead(Col_IO[y]) && (!old_key[x][y])) { //check if key is not pressed, but was previously pressed
          old_key[x][y] = HIGH; // Save state of key as "not pressed"
          if ((normal[x][y] == KEY_SCROLL_LOCK) && (!Fn_pressed)) { // check for special case of Num Lock Key
            clear_slot(KEY_NUM_LOCK); // clear the slot that contains Num Lock
          } else if ((normal[x][y] == KEY_UP) && (!Fn_pressed)) { //media keys
            Keyboard.release(KEY_STOP);
          } else if ((normal[x][y] == KEY_DOWN) && (!Fn_pressed)) {
            Keyboard.release(KEY_PLAYPAUSE);
          } else if ((normal[x][y] == KEY_RIGHT) && (!Fn_pressed)) {
            Keyboard.release(KEY_NEXT);
          } else if ((normal[x][y] == KEY_LEFT) && (!Fn_pressed)) {
            Keyboard.release(KEY_PREVIOUS);
          } else if ((normal[x][y] == KEY_F4) && (!Fn_pressed)) {
            Keyboard.release(KEY_SLEEP);
          } else if ((normal[x][y] == KEY_F5) && (!Fn_pressed)) {
            Keyboard.release(KEY_RADIO_TOGGLE);
          } else if ((normal[x][y] == KEY_HOME) && (!Fn_pressed)) {
            Keyboard.release(KEY_BRIGHTNESS_UP);
          } else if ((normal[x][y] == KEY_END) && (!Fn_pressed)) {
            Keyboard.release(KEY_BRIGHTNESS_DOWN);
          }
          else {
            clear_slot(normal[x][y]); //clear the slot that contains the normal key name
          }
          send_normals(); // send all slots over USB including the key that was just released 
        }
      } 
// **************end of normal section
//
// *************Volume key section. Note PJRC states that volume up, down, & mute should be sent with Keyboard.press function. 
      else if (media[x][y] != 0) {  // check if any volume control key exists at this location in the array (a non-zero value)
        if (!digitalRead(Col_IO[y]) && (old_key[x][y])) { // check if key is pressed and was not previously pressed
          old_key[x][y] = LOW; // Save state of key as "pressed" 
          Keyboard.press(media[x][y]); // send volume key press
        }
        else if (digitalRead(Col_IO[y]) && (!old_key[x][y])) { //check if key is not pressed, but was previously pressed
          old_key[x][y] = HIGH; // Save state of key as "not pressed" 
          Keyboard.release(media[x][y]); // send volume key release 
        }
      }
// ***************end of volume section
    }
    go_z(Row_IO[x]); // De-activate Row (send it to hi-z)
  }
//
// **********keyboard scan complete
//
// ****************************Trackpoint Routine*********************************
//
// poll the trackpoint for new movement data
  over_flow = 0; // assume no overflow until status is received 
  trackpoint_error = LOW; // start with no error
  tp_write(0xeb);  // request data
  if (tp_read() != 0xfa) { // verify correct ack byte
    trackpoint_error = HIGH;
  }
  mstat = tp_read(); // save into status variable
  mx = tp_read(); // save into x variable
  my = tp_read(); // save into y variable
  if (((0x80 & mstat) == 0x80) || ((0x40 & mstat) == 0x40))  {   // x or y overflow bits set?
    over_flow = 1; // set the overflow flag
  }   
// change the x data from 9 bit to 8 bit 2's complement
  //mx = mx >> 1; // convert to 7 bits by dividing by 2 (comment this line out if you want more responsive TP)
  mx = mx & 0x7f; // don't allow sign extension
  if ((0x10 & mstat) == 0x10) {   // move the sign into 
    mx = 0x80 | mx;              // the 8th bit position
  } 
// change the y data from 9 bit to 8 bit 2's complement and then take the 2's complement 
// because y movement on ps/2 format is opposite of touchpad.move function
  //my = my >> 1; // convert to 7 bits by dividing by 2 (comment this line out if you want more responsive TP)
  my = my & 0x7f; // don't allow sign extension
  if ((0x20 & mstat) == 0x20) {   // move the sign into 
    my = 0x80 | my;              // the 8th bit position
  } 
  my = (~my + 0x01); // change the sign of y data by taking the 2's complement (invert and add 1)
// zero out mx and my if over_flow or trackpoint_error is set
  if ((over_flow) || (trackpoint_error)) { 
    mx = 0x00;       // data is garbage so zero it out
    my = 0x00;
  } 
// send the x and y data back via usb if either one is non-zero
  if ((mx != 0x00) || (my != 0x00)) {
    Mouse.move(mx,my);
  }
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
